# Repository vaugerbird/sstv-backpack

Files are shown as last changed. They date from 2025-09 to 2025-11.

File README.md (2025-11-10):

# sstv-backpack
## A ESP32-CAM SSTV backpack for the Baofeng UV-5R and others!

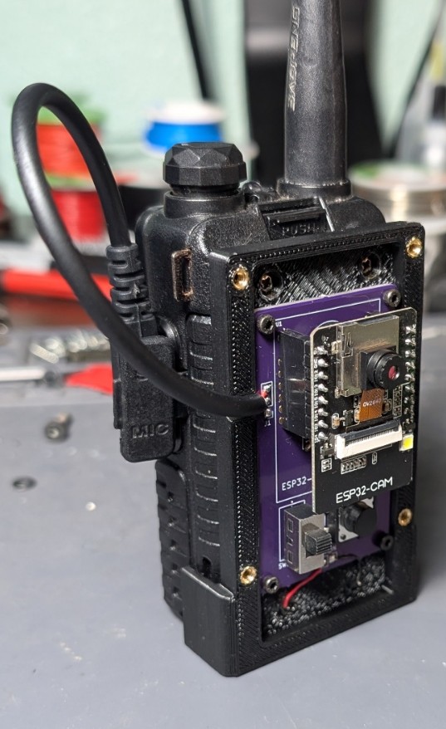
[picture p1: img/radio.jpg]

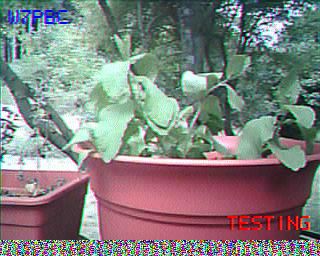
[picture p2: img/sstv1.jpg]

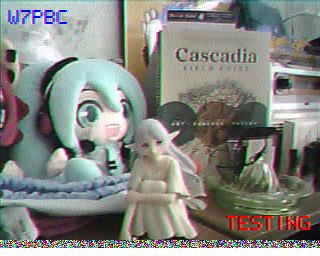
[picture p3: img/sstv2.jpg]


## Project Description
### Turn your HT into a point-and-shoot camera!
This project relies on using an ESP32 connected to a handheld transceiver to send SSTV (Slow Scan TeleVision) images. Any combination of HT and ESP32-CAM can send a picture, but the hardware in this repository is specifically designed to work!

To decode the images, another radio must be used and connected to any device that can run a decoder program. I personally use MMSSTV on my PC with a USB soundcard, or my phone running Robot36 and listening to the radio with the microphone. 

Here's some questions I've been asked in the past:
* **Why?**
    * This is a term project that I created for my college ARC that I'm the president of! We are currently assembling v1.1 and we plan on using the completed projects to do a SSTV scavenger hunt. This consists of a list of things to take pictures of around campus, where the hunter will take a picture of the required object, send the image back to the control room (clubroom), and the point will be awarded to the hunter/team!
* **How does this work?**
    * In short, the ESP32-CAM captures a frame, converts the image into the appropriate encoded audio for SSTV, keys the PTT on the HT, and plays the audio through the microphone port. The specifics of the encoding process are somewhat black magic to me as I didn't create the underlying code, but as far as I understand, the encoding is done by applying a few math functions to the pixels stored in the framebuffer, and converted into audio.

## Hardware Revisions
I currently have 2 hardware revisions available, with a 3rd planned: 
1. v1.0:
    * Mostly through-hole and completely hand-solderable
    * Simplest version with only a voltage regulator circuit, PTT circuit, 2 switches, a buzzer, and the ESP32-CAM
    * Requires external board for flashing and a serial monitor
2. v1.1: 
    * 2 sub-versions:
        * v1.1.1: CH340C version, uses the CH340C for USB-to-UART and has CC resistors for full USB type C compatibility.
        * v1.1.0: FT231XS version, uses the FTDI FT231XS for USB-to-UART and does **not** have CC resistors. I don't recommend this version for many reasons, unless it is difficult to get the CH340C. 
    * Still mostly through-hole and hand-solderable, albeit with some fine-pitch components like the USB-to-UART chip.
    * Retains all the same functionality of v1.0, but adds a USB-to-Serial chip for flashing and a serial monitor.
    * The board is quite cramped and may be hard to work with.
3. v1.2 (WIP):
    * Switch to a mostly top-mounted SMD design, while still being hand-solderable
    * Retain all features of the v1.1 board
    * Maybe add battery charging circuitry?

## Assembly Instructions
### Better (printable) instructions coming soon!
1. Upload your desired [Gerber](./hardware/gerbers/) file to your favorite PCB manufacturer. I recommend OSHPark for US-made, decent-priced priced small-batch PCBs. JLCPCB or PCBWay are both great for cheap, high quality PCBs, if you don't mind waiting.

2. Order the required parts using the proper BOM for [v1.0](./hardware/v1.0/sstv-backpack-v1.0.1.csv) or [v1.1](./hardware/v1.1/sstv-backpack-v1.1.1.csv) from your favorite parts supplier.

3. Once all parts arrive, assemble the board. There isn't much of a technique to it, just start with the lowest profile parts first like the diodes, resistors, and chips, and work your way up.

4. Once the board is complete, print the case using one of the included [STLs](./hardware/case). Currently, the Baofeng UV-5R is the only supported radio, but the Inventor 2025 and STEP files are included, and help with additional radio models is always appreciated!

    * I used the standard settings (0.2mm) on my print, with supports on, and the case interior facing the build plate.

    * The case requires these additional parts:
        * 4 - M3 brass het set inserts
        * 4 - M3 x 6mm screws (preferably hex head)
        * 4 - M2 x 4mm screws
        * 1 - Radio cable (I just cut the end off of a cheap Baofeng speaker-mic, it was cheaper than using an unterminated cable.)

5. After you have the hardware assembled, the next thing to do is upload the code!

## Programming Instructions
1. Ensure that you have this link added to the 3rd party boards section of the Arduino IDE (Found under File -> Preferences -> Additional board manager URLs):
```
https://dl.espressif.com/dl/package_esp32_index.json
```

2. From the board manager, install the newest version of the ESP32 board definitions.

3. Set the board model to "AI Thinker ESP32-CAM" and select the appropriate COM port.

4. Change the text options on lines 37 and 38 of [sstv-backpack.ino](./code/sstv-backpack.ino) to reflect your callsign and desired splash text.
    * The color of the top and bottom text can be changed with the definitions in lines 24-31. 

5. Uncomment line 21 ```#define USE_FLASH``` if you want to use the flash LED (Turns on a high intensity white LED on when framegrabbing).

6. At line 447, set `1 = HIGH` or `0 = LOW` properly reflect your CAPT_BTN wiring (GND for LOW, or +3.3V for HIGH)

7. Between line 452-456, choose the correct button pull-up/pull-down configuration. The button is set to pull-up by default to mirror the PCBs. (Button connects to GND when pressed)

8. Inside the "camera.h" file you can choose between two profiles, DAYLIGHT and HOME. Feel free to modify settings to best suit your case. 
	* Notes from IU5HKU:
		* Keep in mind that this cheap sensor struggles a lot in poor light scenarios, so don't expect a picture like your Fujifilm camera.
		* A quick search online can lead you towards the proper settings values you need.

9. All the board settings can be left alone except for selecting the correct COM port.

10. Upload the code!

## Contributors
 A huge thank you to our contributors for this project! I'm pretty bad with code so all help is greatly appreciated!

 * [IU5HKU / Marco](https://github.com/IU5HKU) - Updated the code to work with the newest version of the ESP32 board definition and improved the readability/usability of the code!
 * [IU5HKU / Marco](https://github.com/IU5HKU) - Updated the code to work with deepsleep/wakeup ESP32 functions (maximize battery life).

## Licensing
* The [main program](./code/sstv-backpack.ino) and [supporting libraries](./code/) are licensed as CC BY-NC-SA 4.0 and are based on the program/libraries from [desafioinventor](https://www.instructables.com/SSTV-Capsule-V2-for-High-Altitude-Balloons/) on Instructables. 
* The case design is roughly based on [this design](https://www.thingiverse.com/thing:5270394) by HStakhiv on [Thingiverse](https://www.thingiverse.com/hstakhiv/designs). The original is licensed under CC BY. My case design falls under the GPL-2.0 license.
* The remaining contents of this repository are designed by me (and contributors!), and are licensed under the GPL-2.0 license.

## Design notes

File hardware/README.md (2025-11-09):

# Hardware
## Currently there are 3 revisions:
* v1.0(.1)
    * Simplest version
    * The board only acts as a voltage regulator, PTT circuit, and carrier for the major parts
* v1.1
    * More complex
    * The board contains the voltage regulator circuit, USB flashing circuit, and PTT circuit
* v1.2
    * Same complexity as v1.1, contains mostly SMD parts

## HW Issues
* v1.0(.1):
    * This board is incapable of flashing the ESP32 or using serial monitor as there is no USB-to-UART chip present. Flashing has to be done with a dedicated programmer and debugging is very difficult. 
* v1.1.0:
    * ~~No CC resistors are present (or really possible) for the USB-C port. This is due to physical restraints of through-hole components, and means the board will not receive power from a USB-C to USB-C cable.~~ Fixed with v1.1.1
    * ~~Powering the board from the radio and connecting USB data is possible, and won't break anything as power is diode-protected, but is not recommended.~~ Fixed with v1.1.1
* v1.2:
    * No issues have been found; this revision of the board has not yet been tested.

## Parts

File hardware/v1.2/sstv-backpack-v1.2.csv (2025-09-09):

Reference | Qty | Value | Part Number | Footprint | Notes
BZ1 | 1 | Buzzer | PS1240P02BT | Buzzer_Beeper:Buzzer_TDK_PS1240P02BT_D12.2mm_H6.5mm
C1,C2 | 2 | 1uF | TAP105K020SCS | Capacitor_THT:C_Disc_D3.4mm_W2.1mm_P2.50mm
C3,C4 | 2 | 47pF | K470J15C0GF5TL2 | Capacitor_THT:C_Disc_D4.7mm_W2.5mm_P5.00mm
C5 | 1 | 10nF | K103K10X7RF5UL2 | Capacitor_THT:C_Disc_D4.7mm_W2.5mm_P5.00mm
C6 | 1 | 100nF | K104K15X7RF5TL2 | Capacitor_THT:C_Disc_D4.7mm_W2.5mm_P5.00mm
D1,D2 | 2 | 1N5819 | 1N5819 | Diode_THT:D_DO-41_SOD81_P7.62mm_Horizontal
D3,D4 | 2 | 1N4148 | 1N4148 | Diode_THT:D_DO-41_SOD81_P7.62mm_Horizontal
J1 | 1 | Conn_01x03_Pin | Optional | Connector_PinHeader_2.54mm:PinHeader_1x03_P2.54mm_Vertical
J2 | 1 | Conn_01x02_Pin | Optional | Connector_PinHeader_2.54mm:PinHeader_1x02_P2.54mm_Vertical
J3 | 1 | 2172034-1 | 2172034-1 | 2172034-1:TE_2172034-1
R1,R2 | 2 | 27Ω | MFR-25FTE52-27R | Resistor_THT:R_Axial_DIN0207_L6.3mm_D2.5mm_P7.62mm_Horizontal
SW1 | 1 | SW_Push | PTS125SM73SMTR21M LFS
SW2 | 1 | SLW-1276864-4A-D | SLW-1276864-4A-D | SwitchSPDT:SW_SLW-1276864-4A-D
U1 | 1 | ESP32-CAM | See note → | ESP32-CAM:ESP32-CAM | I recommend ordering this from Amazon
U1 | 2 | 1X8 FEM HEADERS | PPTC081LFBN-RC | ESP32-CAM:ESP32-CAM
U2 | 1 | FT231XS | FT231XS-R | Package_SO:SSOP-20_3.9x8.7mm_P0.635mm
VR1 | 1 | LP38693DT-5.0 | LP38691DTX-5.0/NOPB | Package_TO_SOT_SMD:TO-252-2

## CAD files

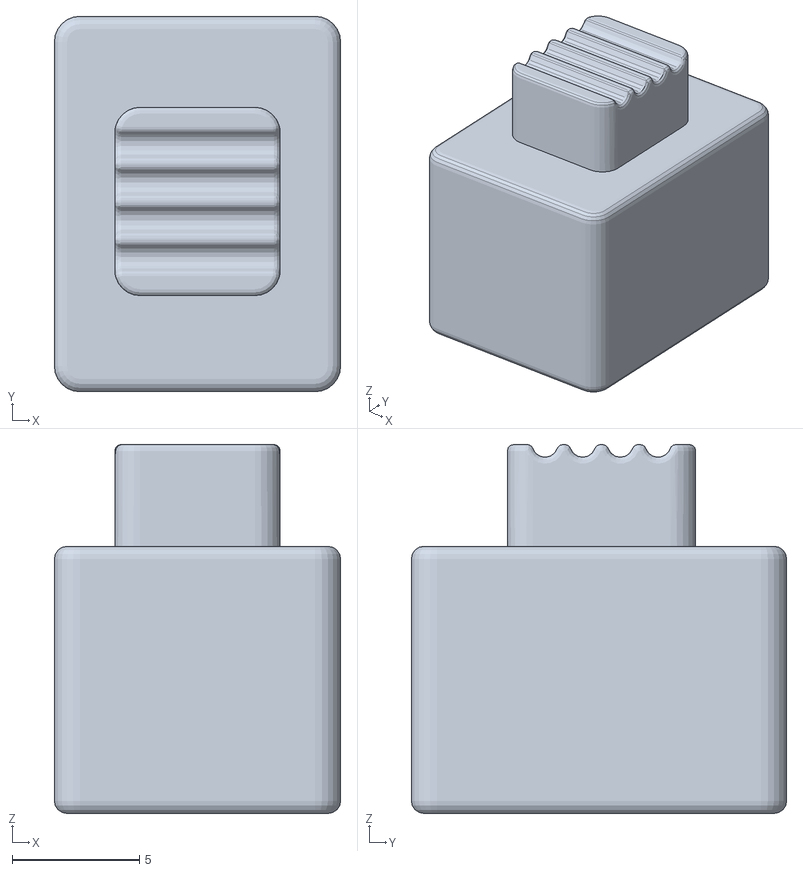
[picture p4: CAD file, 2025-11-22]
hardware/case/Universal/switch.stl
11.2 x 14.8 x 14.5

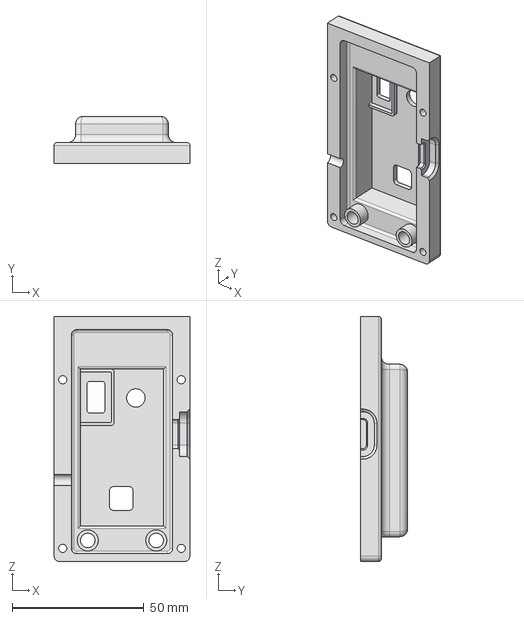
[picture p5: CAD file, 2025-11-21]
hardware/case/UV-5R/STEP/uv-5r-front.stp
51.5 x 18.0 x 93.0 mm

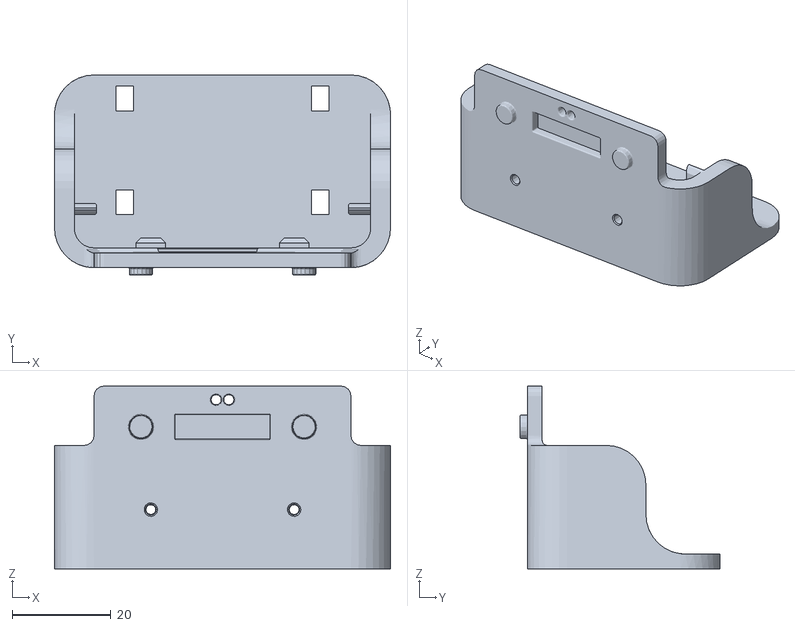
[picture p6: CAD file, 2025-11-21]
hardware/case/UV-5RM/5RM_batt_conn.stl
68.0 x 40.5 x 37.0

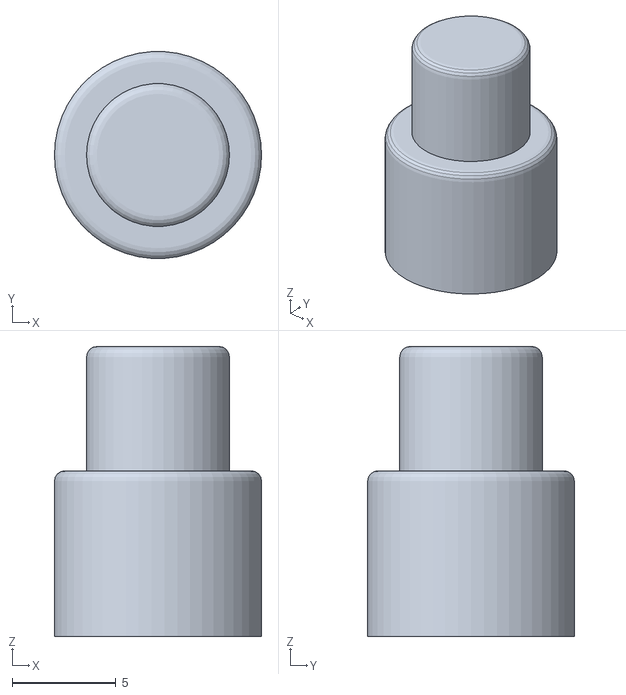
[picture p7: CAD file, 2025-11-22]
hardware/case/Universal/button.stl
10.0 x 9.98 x 14.0

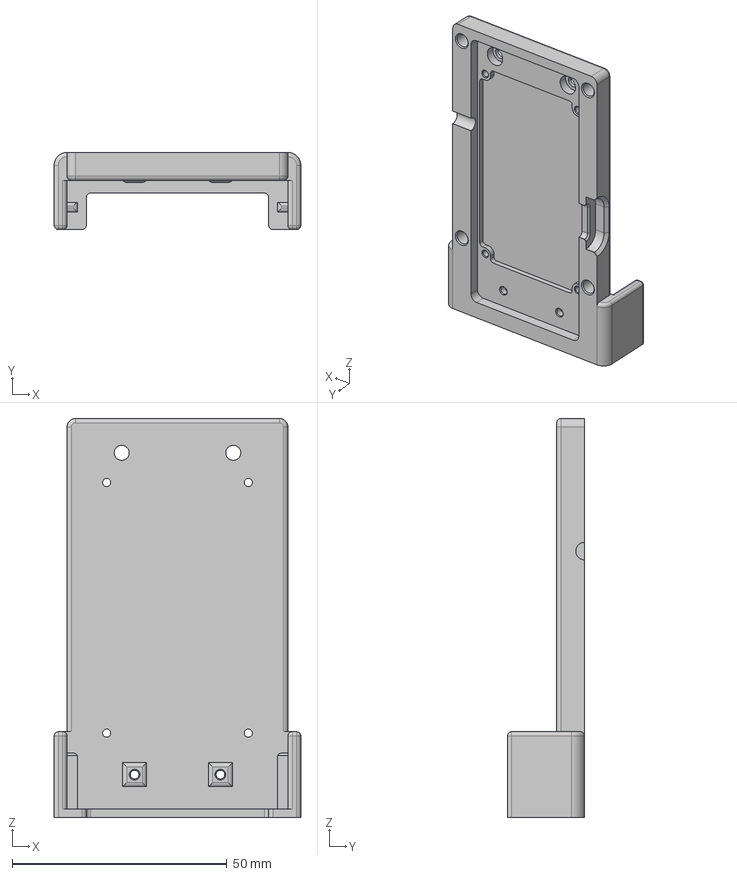
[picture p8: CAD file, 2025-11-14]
hardware/case/UV-5R/STEP/uv-5r-back.stp
57.5 x 18.0 x 93.0 mm

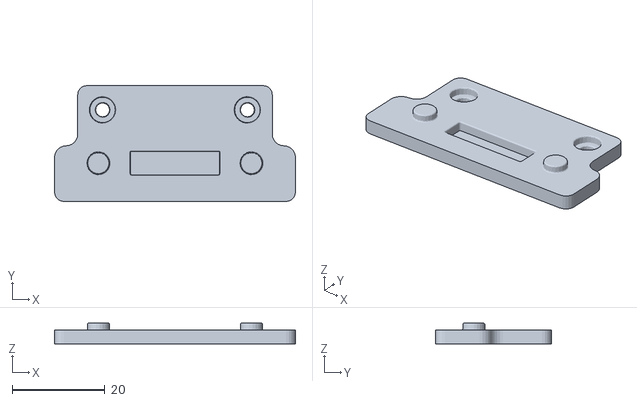
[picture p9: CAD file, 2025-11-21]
hardware/case/UV-5RM/5RM_belt_clip.stl
52.0 x 25.0 x 4.50

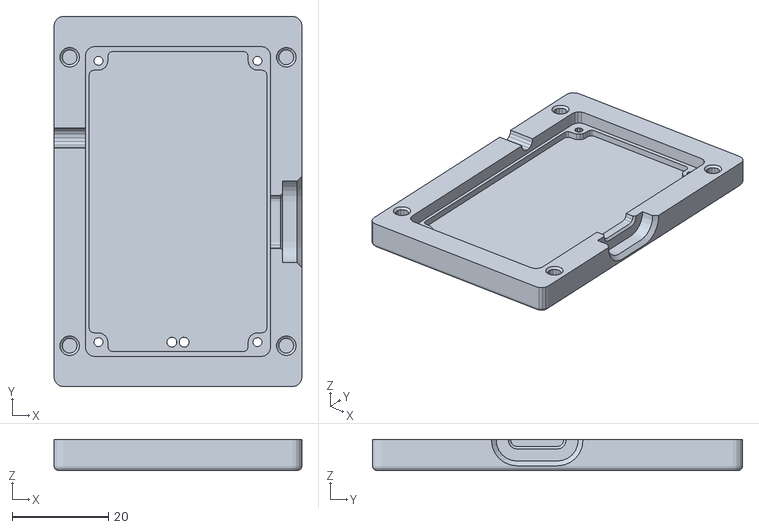
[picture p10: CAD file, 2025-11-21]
hardware/case/Universal/universal_case_back.stl
51.5 x 76.9 x 6.50

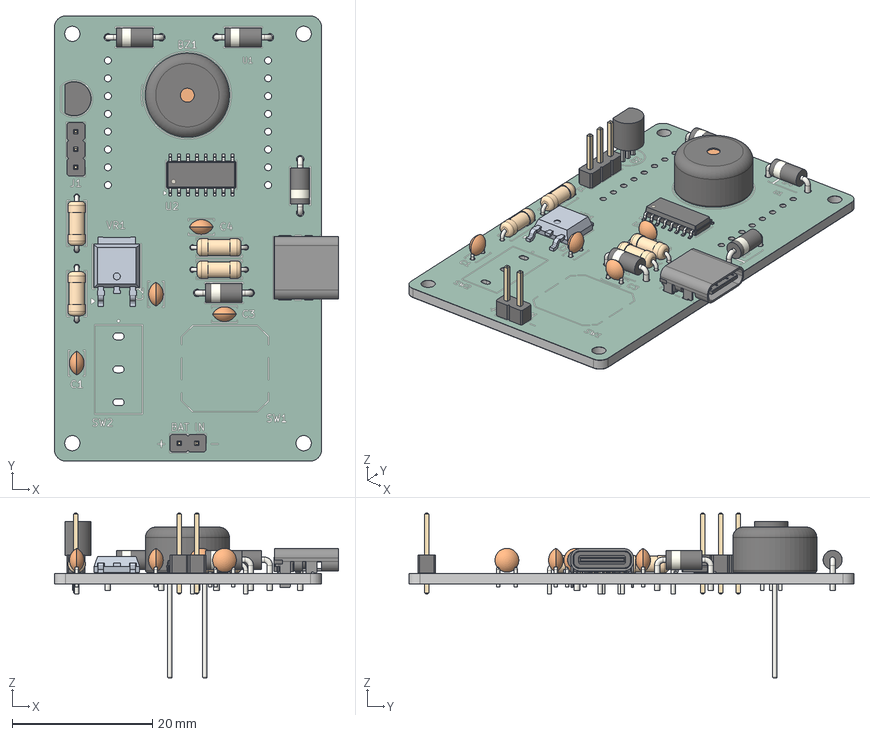
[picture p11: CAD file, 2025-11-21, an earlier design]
hardware/v1.1/sstv-backpack.step
40.5 x 63.5 x 23.5 mm
sstv-backpack 1.1.1
Buzzer_TDK_PS1240P02BT_D12.2mm_H6.5mm
R_Axial_DIN0207_L6.3mm_D2.5mm_P7.62mm_Horizontal x 4
D_DO-41_SOD81_P7.62mm_Horizontal x 4
C_Disc_D3.4mm_W2.1mm_P2.50mm x 4
PinHeader_1x02_P2.54mm_Vertical
SOIC-16_3.9x9.9mm_P1.27mm
PinHeader_1x03_P2.54mm_Vertical
USB_C_Receptacle_GCT_USB4085
TO-92_Inline
sstv-backpack-v1.1.1_silkscreen x 2
sstv-backpack-v1.1.1_soldermask x 2
sstv-backpack-v1.1.1_PCB

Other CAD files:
hardware/case/UV-5R/Inventor (2025)/uv-5r-back.ipt
hardware/case/UV-5R/Inventor (2025)/uv-5r-front.ipt
hardware/case/UV-5R/uv-5r-back.stl
hardware/case/UV-5R/uv-5r-front.stl
hardware/case/UV-5RM/Inventor (2025)/5RM_batt_conn.ipt
hardware/case/UV-5RM/Inventor (2025)/5RM_belt_clip.ipt
hardware/case/Universal/Inventor (2025)/button.ipt
hardware/case/Universal/Inventor (2025)/switch.ipt
hardware/case/Universal/Inventor (2025)/universal_case_back.ipt
hardware/v1.1/sstv-backpack/Buzzer_TDK_PS1240P02BT_D12.2mm_H6.5mm.ipt
hardware/v1.1/sstv-backpack/C_Disc_D3.4mm_W2.1mm_P2.50mm.ipt
hardware/v1.1/sstv-backpack/D_DO-41_SOD81_P7.62mm_Horizontal.ipt
hardware/v1.1/sstv-backpack/PinHeader_1x02_P2.54mm_Vertical.ipt
hardware/v1.1/sstv-backpack/PinHeader_1x03_P2.54mm_Vertical.ipt
hardware/v1.1/sstv-backpack/R_Axial_DIN0207_L6.3mm_D2.5mm_P7.62mm_Horizontal.ipt
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

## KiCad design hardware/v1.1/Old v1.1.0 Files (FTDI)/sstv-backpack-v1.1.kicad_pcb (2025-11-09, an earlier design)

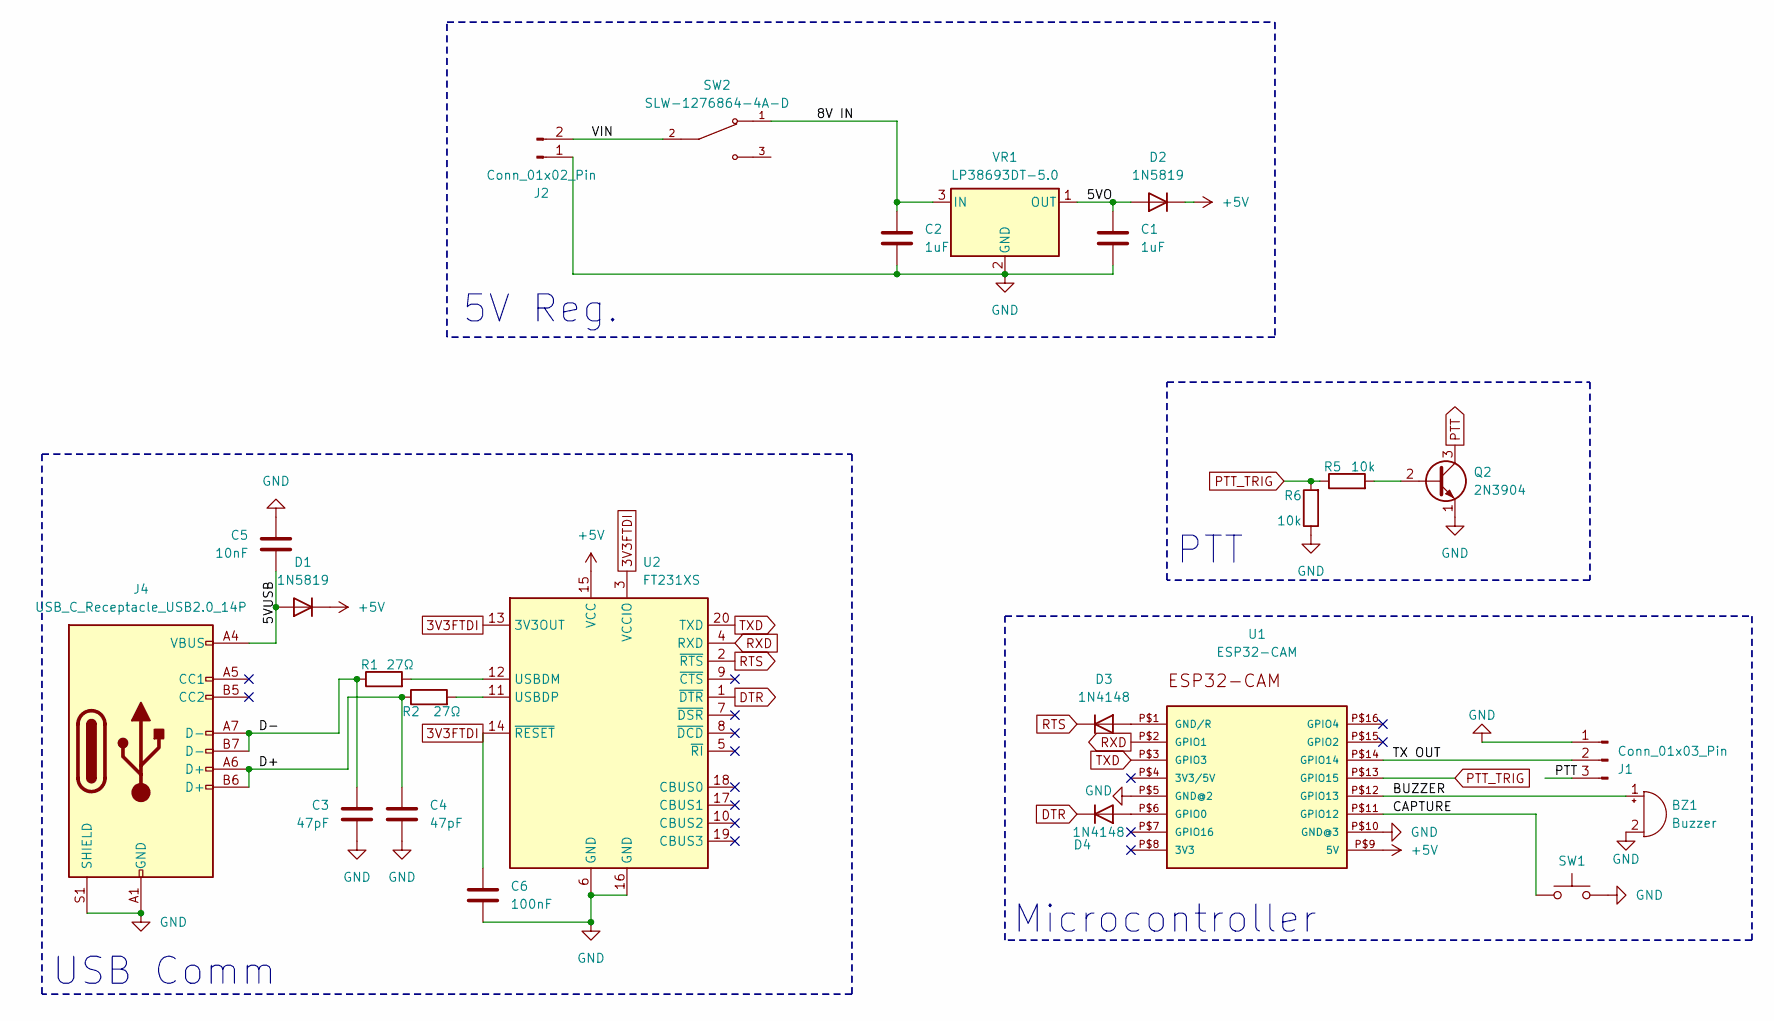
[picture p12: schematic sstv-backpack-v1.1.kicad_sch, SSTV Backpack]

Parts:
BZ1: Buzzer; Buzzer_TDK_PS1240P02BT_D12.2mm_H6.5mm
C1, C2: 1uF; C_Disc_D3.4mm_W2.1mm_P2.50mm
C3, C4: 47pF; C_Disc_D4.7mm_W2.5mm_P5.00mm
C5: 10nF; C_Disc_D4.7mm_W2.5mm_P5.00mm
C6: 100nF; C_Disc_D4.7mm_W2.5mm_P5.00mm
D1, D2: 1N5819; D_DO-41_SOD81_P7.62mm_Horizontal
D3, D4: 1N4148; D_DO-41_SOD81_P7.62mm_Horizontal
J1: Conn_01x03_Pin; PinHeader_1x03_P2.54mm_Vertical
J2: Conn_01x02_Pin; PinHeader_1x02_P2.54mm_Vertical
J4: USB_C_Receptacle_USB2.0_14P; USB_C_Receptacle_GCT_USB4085
Q2: 2N3904; TO-92_Inline
R1, R2: 27Ω; R_Axial_DIN0207_L6.3mm_D2.5mm_P7.62mm_Horizontal
R5, R6: 10k; R_Axial_DIN0207_L6.3mm_D2.5mm_P7.62mm_Horizontal
SW1: SW_Push
SW2: SLW-1276864-4A-D; SW_SLW-1276864-4A-D; PARTREV 1.01
U1: ESP32-CAM
U2: FT231XS; SSOP-20_3.9x8.7mm_P0.635mm
VR1: LP38693DT-5.0; TO-252-2

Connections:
3V3FTDI: C6.1, U2.3 (VCCIO), U2.13 (3V3OUT), U2.14 (~RESET)
+5V: D1.1 (K), D2.1 (K), U1.P$9 (5V), U2.15 (VCC)
/5VO: C1.1, D2.2 (A), VR1.1 (OUT)
/5VUSB: C5.2, D1.2 (A), J4.A4 (VBUS), J4.A9 (VBUS), J4.B4 (VBUS), J4.B9 (VBUS)
/8V IN: C2.1, SW2.1, VR1.3 (IN)
/BUZZER: BZ1.1 (+), U1.P$12 (GPIO13)
/CAPTURE: SW1.1, U1.P$11 (GPIO12)
/D+: C4.1, J4.A6 (D+), J4.B6 (D+), R2.1
/D-: C3.1, J4.A7 (D-), J4.B7 (D-), R1.1
/TX OUT: J1.2, U1.P$14 (GPIO14)
/VIN: J2.2, SW2.2
DTR: D4.1 (K), U2.1 (~DTR)
GND: BZ1.2 (-), C1.2, C2.2, C3.2, C4.2, C5.1, C6.2, J1.1, J2.1, J4.A1 (GND), J4.A12 (GND), J4.B1 (GND), J4.B12 (GND), J4.S1 (SHIELD), Q2.1 (E), R6.1, SW1.2, U1.P$5 (GND@2), U1.P$10 (GND@3), U2.6 (GND), U2.16 (GND), VR1.2 (GND)
unnamed: D3.2 (A), U1.P$1 (GND/R)
unnamed: D4.2 (A), U1.P$6 (GPIO0)
unnamed: Q2.2 (B), R5.2
unnamed: R1.2, U2.12 (USBDM)
unnamed: R2.2, U2.11 (USBDP)
PTT: J1.3, Q2.3 (C)
PTT_TRIG: R5.1, R6.2, U1.P$13 (GPIO15)
RTS: D3.1 (K), U2.2 (~RTS)
RXD: U1.P$2 (GPIO1), U2.4 (RXD)
TXD: U1.P$3 (GPIO3), U2.20 (TXD)

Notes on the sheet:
5V Reg.
Microcontroller
USB Comm
PTT

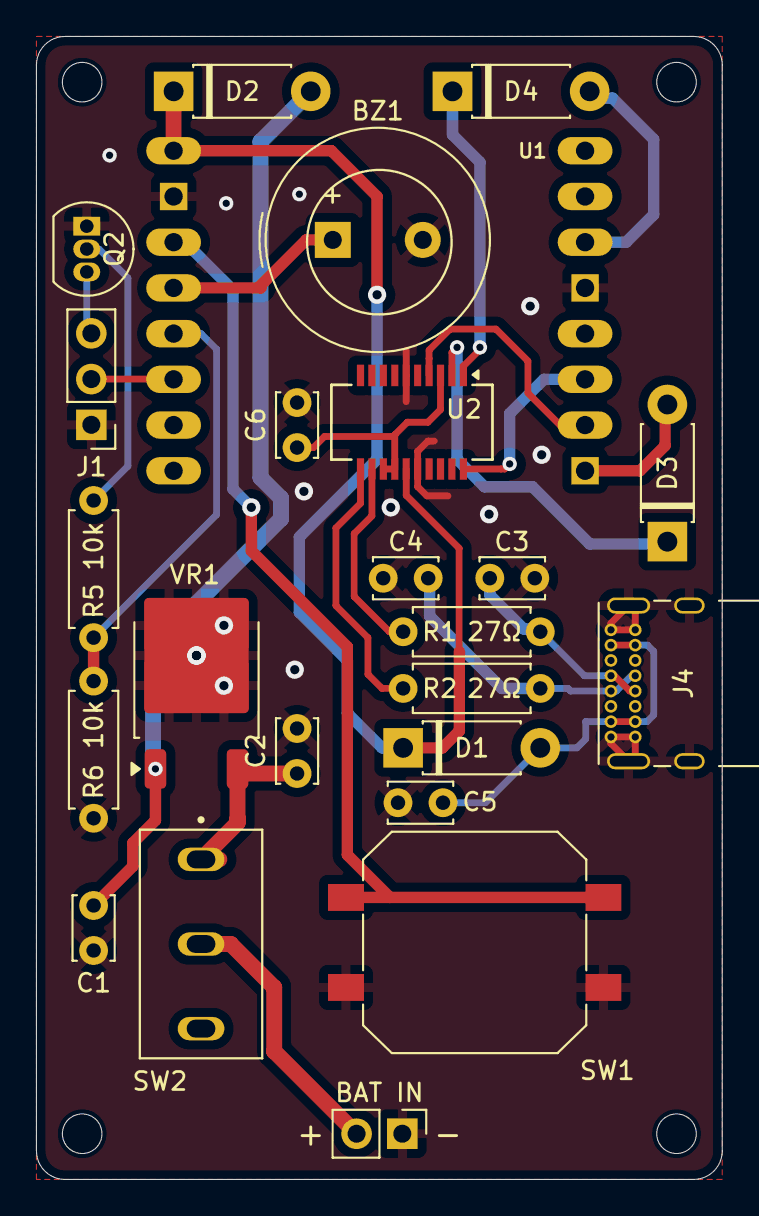
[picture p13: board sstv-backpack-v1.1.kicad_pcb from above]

Board: 2 copper layers, 38.1 x 63.5 mm, 24 parts (0 on the bottom side), 23 nets.

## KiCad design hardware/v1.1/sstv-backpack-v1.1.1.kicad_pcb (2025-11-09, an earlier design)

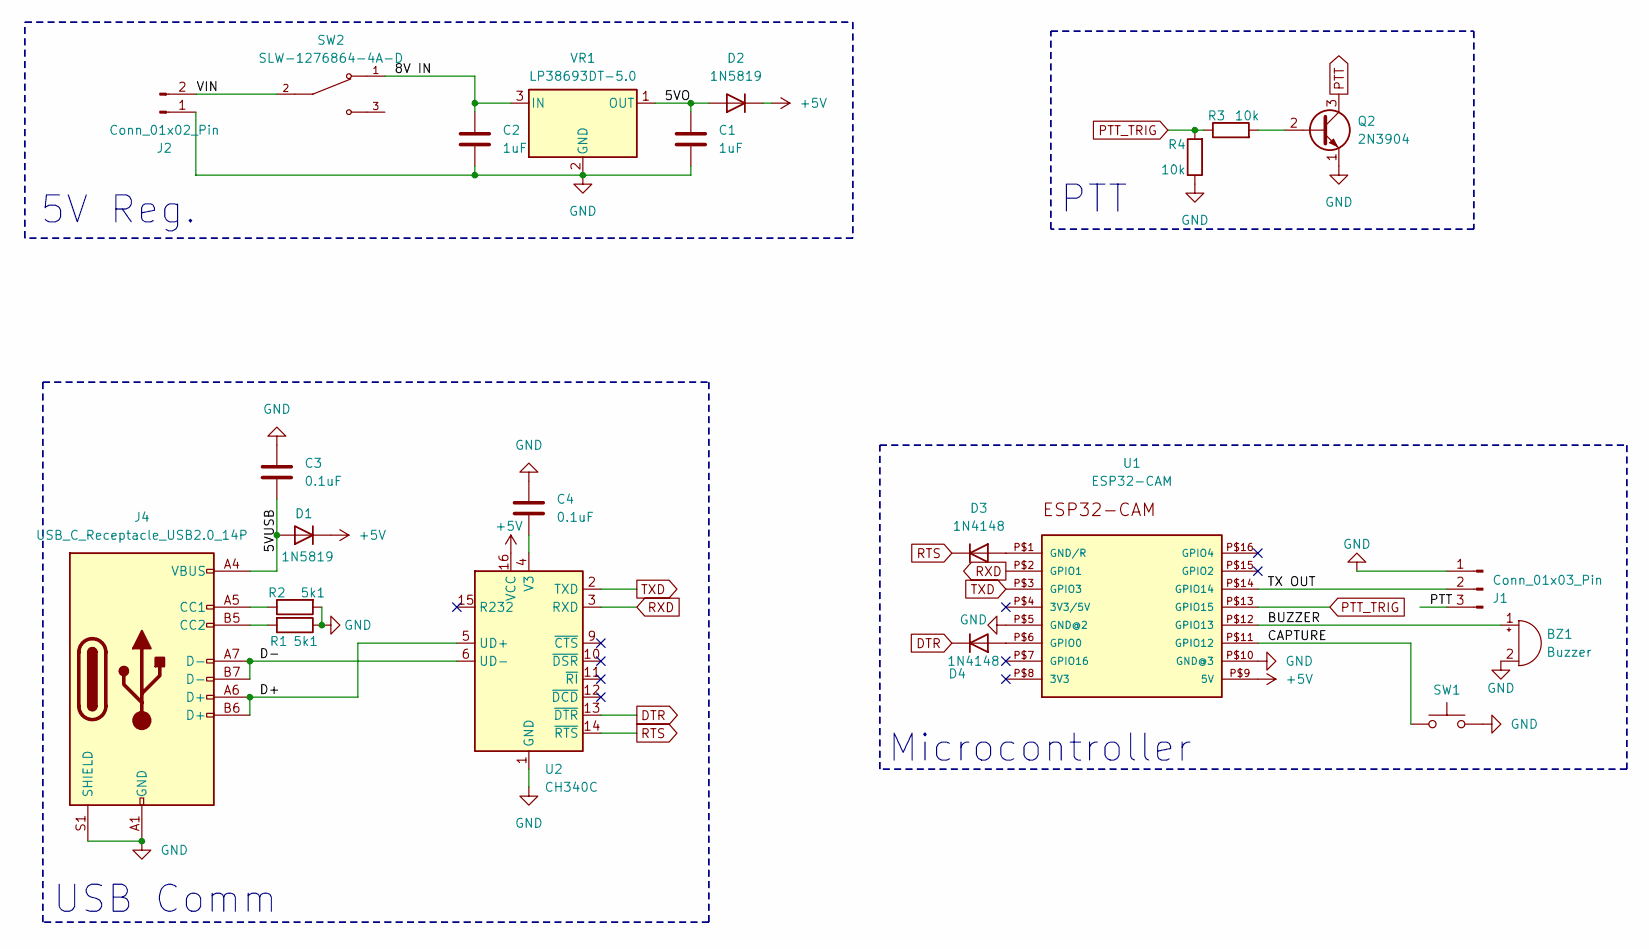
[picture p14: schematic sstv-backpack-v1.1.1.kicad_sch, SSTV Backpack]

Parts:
BZ1: Buzzer; Buzzer_TDK_PS1240P02BT_D12.2mm_H6.5mm
C1, C2: 1uF; C_Disc_D3.4mm_W2.1mm_P2.50mm
C3, C4: 0.1uF; C_Disc_D3.4mm_W2.1mm_P2.50mm
D1, D2: 1N5819; D_DO-41_SOD81_P7.62mm_Horizontal
D3, D4: 1N4148; D_DO-41_SOD81_P7.62mm_Horizontal
J1: Conn_01x03_Pin; PinHeader_1x03_P2.54mm_Vertical
J2: Conn_01x02_Pin; PinHeader_1x02_P2.54mm_Vertical
J4: USB_C_Receptacle_USB2.0_14P; USB_C_Receptacle_GCT_USB4085
Q2: 2N3904; TO-92_Inline
R1, R2: 5k1; R_Axial_DIN0207_L6.3mm_D2.5mm_P7.62mm_Horizontal
R3, R4: 10k; R_Axial_DIN0207_L6.3mm_D2.5mm_P7.62mm_Horizontal
SW1: SW_Push
SW2: SLW-1276864-4A-D; SW_SLW-1276864-4A-D; PARTREV 1.01
U1: ESP32-CAM
U2: CH340C; SOIC-16_3.9x9.9mm_P1.27mm
VR1: LP38693DT-5.0; TO-252-2

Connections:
+5V: D1.1 (K), D2.1 (K), U1.P$9 (5V), U2.16 (VCC)
/5VO: C1.1, D2.2 (A), VR1.1 (OUT)
/5VUSB: C3.2, D1.2 (A), J4.A4 (VBUS), J4.A9 (VBUS), J4.B4 (VBUS), J4.B9 (VBUS)
/8V IN: C2.1, SW2.1, VR1.3 (IN)
/BUZZER: BZ1.1 (+), U1.P$12 (GPIO13)
/CAPTURE: SW1.1, U1.P$11 (GPIO12)
/D+: J4.A6 (D+), J4.B6 (D+), U2.5 (UD+)
/D-: J4.A7 (D-), J4.B7 (D-), U2.6 (UD-)
/TX OUT: J1.2, U1.P$14 (GPIO14)
/VIN: J2.2, SW2.2
DTR: D4.1 (K), U2.13 (~DTR)
GND: BZ1.2 (-), C1.2, C2.2, C3.1, C4.1, J1.1, J2.1, J4.A1 (GND), J4.A12 (GND), J4.B1 (GND), J4.B12 (GND), J4.S1 (SHIELD), Q2.1 (E), R1.1, R2.2, R4.1, SW1.2, U1.P$5 (GND@2), U1.P$10 (GND@3), U2.1 (GND), VR1.2 (GND)
unnamed: D3.2 (A), U1.P$1 (GND/R)
unnamed: D4.2 (A), U1.P$6 (GPIO0)
unnamed: J4.A5 (CC1), R2.1
unnamed: J4.B5 (CC2), R1.2
unnamed: Q2.2 (B), R3.2
unnamed: C4.2, U2.4 (V3)
PTT: J1.3, Q2.3 (C)
PTT_TRIG: R3.1, R4.2, U1.P$13 (GPIO15)
RTS: D3.1 (K), U2.14 (~RTS)
RXD: U1.P$2 (GPIO1), U2.3 (RXD)
TXD: U1.P$3 (GPIO3), U2.2 (TXD)

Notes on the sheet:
5V Reg.
Microcontroller
USB Comm
PTT

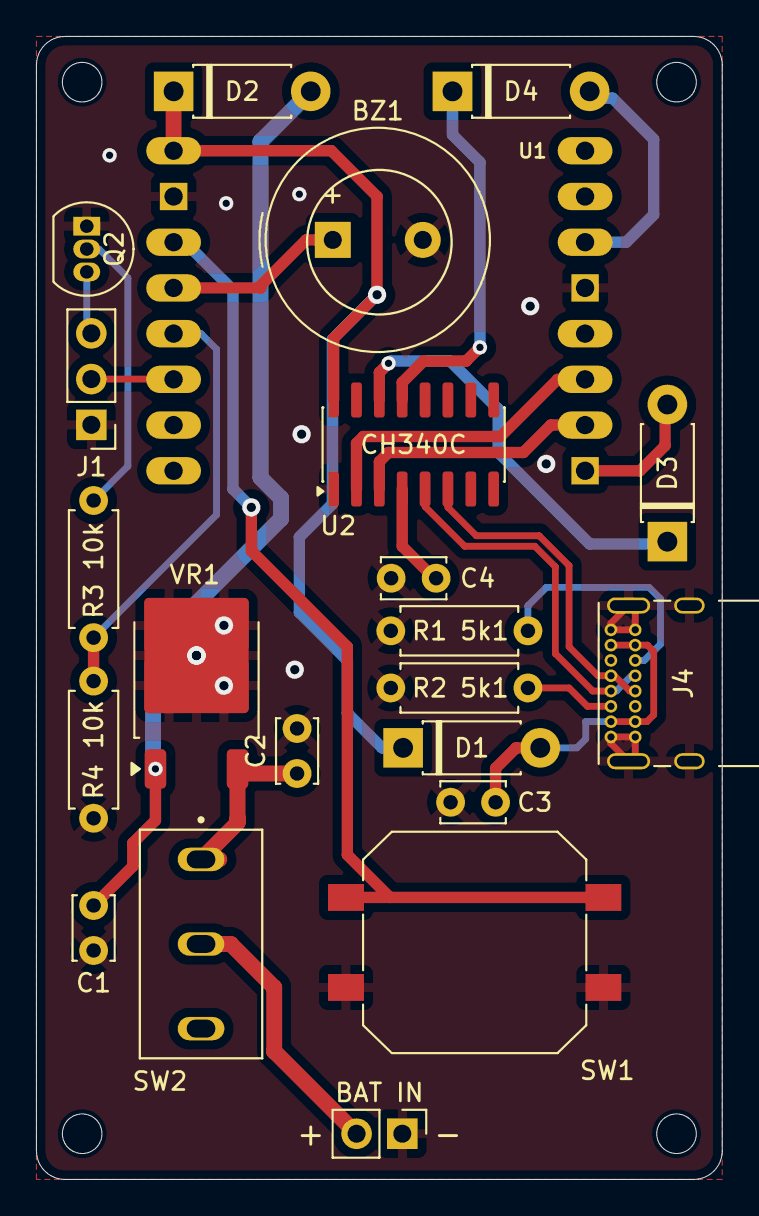
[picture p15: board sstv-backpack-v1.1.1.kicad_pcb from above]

Board: 2 copper layers, 38.1 x 63.5 mm, 22 parts (0 on the bottom side), 23 nets.

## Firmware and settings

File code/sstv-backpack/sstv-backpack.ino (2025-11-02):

#include <driver/ledc.h>
#include "camera.h"
#include "sin256.h"
#include <esp_task_wdt.h>
#include <driver/rtc_io.h>
#include <WiFi.h>

#define BELL202_BAUD 1200
#define F_SAMPLE ((BELL202_BAUD * 32) * 0.93) // ≈ 35712 Hz
#define FTOFTW (4294967295 / F_SAMPLE)
#define TIME_PER_SAMPLE (1000.0/F_SAMPLE)
#define uS_TO_S_FACTOR 1000000
#define TIME_TO_SLEEP  5

#define LED_FLASH       4
#define LED_RED         33
#define SPEAKER_OUTPUT  14
#define PTT_PIN         15      // Pin for PTT (HIGH = active)
#define BUZZER_PIN      13   // Pin for indication buzzer
#define CAPT_BTN        GPIO_NUM_12     // Pin for button to activate capture
//#define USE_FLASH     // Uncomment to use the onboard high intensity white LED as flash

// TOP STRING COLOR (default cyan, the most readable)
#define TOP_R  0
#define TOP_G  255
#define TOP_B  255

// BOTTOM STRING COLOR (default cyan, the most readable)
#define BTM_R  0
#define BTM_G  255
#define BTM_B  255

bool capt_frame = false;

int start = 0;

String overlayTextTop = "CALLSIGN_HERE";    // Upper left
String overlayTextBottom = "SUBTEXT_HERE"; // Lower right

volatile uint32_t FTW = FTOFTW * 1000;
volatile uint32_t PCW = 0;
volatile uint32_t TFLAG = 0;

#define FT_1000 (uint32_t) (1000 * FTOFTW)
#define FT_1100 (uint32_t) (1100 * FTOFTW)
#define FT_1200 (uint32_t) (1200 * FTOFTW)
#define FT_1300 (uint32_t) (1300 * FTOFTW)
#define FT_1500 (uint32_t) (1500 * FTOFTW)
#define FT_1900 (uint32_t) (1900 * FTOFTW)
#define FT_2200 (uint32_t) (2200 * FTOFTW)
#define FT_2300 (uint32_t) (2300 * FTOFTW)
#define FT_SYNC (uint32_t) (FT_1200)

#define MAX_WIDTH 320
#define MAX_HEIGHT 256

class SSTV_config_t {
  public:
    uint8_t vis_code;
    uint32_t width;
    uint32_t height;
    float line_time;
    float h_sync_time;
    float v_sync_time;
    float c_sync_time;
    float left_margin_time;
    float visible_pixels_time;
    float pixel_time;
    bool color;
    bool martin;
    bool robot;

    SSTV_config_t(uint8_t v) {
      vis_code = v;
      switch (vis_code) {
        case 2: // Robot B&W8
          robot = true; martin = false; color = false;
          width = 160; height = 120;
          line_time = 67.025; h_sync_time = 30.0; v_sync_time = 6.5;
          left_margin_time = 1.6;
          visible_pixels_time = line_time - v_sync_time - left_margin_time;
          pixel_time = visible_pixels_time / width;
          break;
        case 44: // Martin M1
          robot = false; martin = true; color = true;
          width = 320; height = 240;
          line_time = 446.4460001; h_sync_time = 30.0; v_sync_time = 4.862;
          c_sync_time = 0.572; left_margin_time = 0.0;
          visible_pixels_time = line_time - v_sync_time - left_margin_time - (2 * c_sync_time);
          pixel_time = visible_pixels_time / (width * 3);
          break;
      }
    }
};

camera_fb_t* fb;

SSTV_config_t* currentSSTV;

volatile uint16_t rasterX = 0;
volatile uint16_t rasterY = 0;
volatile uint8_t SSTVseq = 0;
double SSTVtime = 0;
double SSTVnext = 0;
uint8_t VISsr = 0;
uint8_t VISparity;
uint8_t HEADERptr = 0;
static uint32_t SSTV_HEADER[] = {FT_2300, 100, FT_1500, 100, FT_2300, 100, FT_1500, 100, FT_1900, 300, FT_1200, 10, FT_1900, 300, FT_1200, 30, 0, 0};
uint8_t SSTV_RUNNING = 0;

uint8_t *rgb_buf = NULL;
uint32_t rgb_buf_len;
uint16_t rgb_width;
uint16_t rgb_height;

TaskHandle_t sampleHandlerHandle;

void IRAM_ATTR audioISR() {
  PCW += FTW;
  TFLAG = 1;
}

/*******************************************************
 * FUNCTION: print_wakeup_reason
 * DESCRIPTION: Prints the cause of the ESP32 waking up
 * from Deep Sleep (Timer, external signal, etc.) to the serial monitor.
 * INPUT: None
 * OUTPUT: None
 *******************************************************/
void print_wakeup_reason(){
  esp_sleep_wakeup_cause_t wakeup_reason;

  wakeup_reason = esp_sleep_get_wakeup_cause();

  switch(wakeup_reason)
  {
    case ESP_SLEEP_WAKEUP_EXT0 : 
      {
        Serial.println("Wakeup caused by external signal using RTC_IO");
        capt_frame = true;
      }
      break;
    case ESP_SLEEP_WAKEUP_EXT1 : Serial.println("Wakeup caused by external signal using RTC_CNTL"); break;
    case ESP_SLEEP_WAKEUP_TIMER : Serial.println("Wakeup caused by timer"); break;
    case ESP_SLEEP_WAKEUP_TOUCHPAD : Serial.println("Wakeup caused by touchpad"); break;
    case ESP_SLEEP_WAKEUP_ULP : Serial.println("Wakeup caused by ULP program"); break;
    default : Serial.printf("Wakeup was not caused by deep sleep: %d\n",wakeup_reason); break;
  }
}

void sampleHandler(void *p) {
  disableCore0WDT();
  while (1) {
    if (TFLAG) {
      TFLAG = 0;
      int v = SinTableH[((uint8_t*)&PCW)[3]];
      ledcWrite(SPEAKER_OUTPUT, v); // modulate the selected pin in PWM
      SSTVtime += TIME_PER_SAMPLE;
      if (!SSTV_RUNNING || SSTVtime < SSTVnext) continue;

      switch (SSTVseq) {
        case 0: // Start
          SSTVtime = 0; HEADERptr = 0; VISparity = 0; VISsr = currentSSTV->vis_code;
          FTW = SSTV_HEADER[HEADERptr++]; SSTVnext = (float)SSTV_HEADER[HEADERptr++];
          SSTVseq++; break;
        case 1: // VIS header
          if (SSTV_HEADER[HEADERptr + 1] == 0) {
            SSTVseq++; HEADERptr = 0;
          } else {
            FTW = SSTV_HEADER[HEADERptr++]; SSTVnext += (float)SSTV_HEADER[HEADERptr++];
          }
          break;
        case 2: // VIS code
          if (HEADERptr == 7) {
            HEADERptr = 0;
            FTW = VISparity ? FT_1100 : FT_1300;
            SSTVnext += 30.0; SSTVseq++;
          } else {
            FTW = (VISsr & 0x01) ? (VISparity ^= 0x01, FT_1100) : FT_1300;
            VISsr >>= 1; SSTVnext += 30.0; HEADERptr++;
          }
          break;
        case 3: // VIS stop bit/sync0
          FTW = FT_1200; SSTVnext += 30.0 + currentSSTV->h_sync_time;
          rasterX = 0; rasterY = 0; SSTVseq = 10; break;
        case 10: // Start of line Green
          if (rasterX == currentSSTV->width) {
            rasterX = 0; FTW = FT_1500; SSTVnext += currentSSTV->c_sync_time; SSTVseq++;
          } else {
            int G = rgb_buf[1 + (rasterX * 3) + (rasterY * currentSSTV->width * 3)];
            int f = map(G, 0, 255, 1500, 2300); FTW = FTOFTW * f;
            SSTVnext += currentSSTV->pixel_time; rasterX++;
          }
          break;
        case 11: // Blue
          if (rasterX == currentSSTV->width) {
            rasterX = 0; FTW = FT_1500; SSTVnext += currentSSTV->c_sync_time; SSTVseq++;
          } else {
            int B = rgb_buf[(rasterX * 3) + (rasterY * currentSSTV->width * 3)];
            int f = map(B, 0, 255, 1500, 2300); FTW = FTOFTW * f;
            SSTVnext += currentSSTV->pixel_time; rasterX++;
          }
          break;
        case 12: // Red
          if (rasterX == currentSSTV->width) {
            rasterX = 0; rasterY++;
            if (rasterY == currentSSTV->height) {
              SSTV_RUNNING = false; SSTVseq = 0; FTW = 0; PCW = 0;
            } else {
              FTW = FT_SYNC; SSTVnext += currentSSTV->v_sync_time; SSTVseq = 10;
            }
          } else {
            int R = rgb_buf[2 + (rasterX * 3) + (rasterY * currentSSTV->width * 3)];
            int f = map(R, 0, 255, 1500, 2300); FTW = FTOFTW * f;
            SSTVnext += currentSSTV->pixel_time; rasterX++;
          }
          break;
      }
    }
  }
}

void drawText(uint8_t *rgb_buf, uint16_t width, uint16_t height, const char *text_top, const char *text_bottom) {
  if (!rgb_buf) return;

  int char_width = 10;
  int char_height = 14;
  int spacing = 2;

  const uint8_t font[36][7] = {
    {0b01110, 0b10001, 0b10001, 0b11111, 0b10001, 0b10001, 0b10001}, // A
    {0b11110, 0b10001, 0b10001, 0b11110, 0b10001, 0b10001, 0b11110}, // B
    {0b01111, 0b10000, 0b10000, 0b10000, 0b10000, 0b10000, 0b01111}, // C
    {0b11110, 0b10001, 0b10001, 0b10001, 0b10001, 0b10001, 0b11110}, // D
    {0b11111, 0b10000, 0b10000, 0b11110, 0b10000, 0b10000, 0b11111}, // E
    {0b11111, 0b10000, 0b10000, 0b11110, 0b10000, 0b10000, 0b10000}, // F
    {0b01111, 0b10000, 0b10000, 0b10011, 0b10001, 0b10001, 0b01111}, // G
    {0b10001, 0b10001, 0b10001, 0b11111, 0b10001, 0b10001, 0b10001}, // H
    {0b00100, 0b00100, 0b00100, 0b00100, 0b00100, 0b00100, 0b00100}, // I
    {0b00001, 0b00001, 0b00001, 0b00001, 0b00001, 0b10001, 0b01110}, // J
    {0b10001, 0b10010, 0b10100, 0b11000, 0b10100, 0b10010, 0b10001}, // K
    {0b10000, 0b10000, 0b10000, 0b10000, 0b10000, 0b10000, 0b11111}, // L
    {0b10001, 0b11011, 0b10101, 0b10001, 0b10001, 0b10001, 0b10001}, // M
    {0b10001, 0b10001, 0b11001, 0b10101, 0b10011, 0b10001, 0b10001}, // N
    {0b01110, 0b10001, 0b10001, 0b10001, 0b10001, 0b10001, 0b01110}, // O
    {0b11110, 0b10001, 0b10001, 0b11110, 0b10000, 0b10000, 0b10000}, // P
    {0b01110, 0b10001, 0b10001, 0b10001, 0b10101, 0b10010, 0b01101}, // Q
    {0b11110, 0b10001, 0b10001, 0b11110, 0b10100, 0b10010, 0b10001}, // R
    {0b01111, 0b10000, 0b10000, 0b01110, 0b00001, 0b00001, 0b11110}, // S
    {0b11111, 0b00100, 0b00100, 0b00100, 0b00100, 0b00100, 0b00100}, // T
    {0b10001, 0b10001, 0b10001, 0b10001, 0b10001, 0b10001, 0b01110}, // U
    {0b10001, 0b10001, 0b10001, 0b10001, 0b10001, 0b01010, 0b00100}, // V
    {0b10001, 0b10001, 0b10001, 0b10101, 0b10101, 0b10101, 0b01010}, // W
    {0b10001, 0b10001, 0b01010, 0b00100, 0b01010, 0b10001, 0b10001}, // X
    {0b10001, 0b10001, 0b10001, 0b01010, 0b00100, 0b00100, 0b00100}, // Y
    {0b11111, 0b00001, 0b00010, 0b00100, 0b01000, 0b10000, 0b11111}, // Z
    {0b01110, 0b10001, 0b10001, 0b10001, 0b10001, 0b10001, 0b01110}, // 0
    {0b00100, 0b01100, 0b00100, 0b00100, 0b00100, 0b00100, 0b01110}, // 1
    {0b01110, 0b10001, 0b00001, 0b00110, 0b01000, 0b10000, 0b11111}, // 2
    {0b01110, 0b10001, 0b00001, 0b00110, 0b00001, 0b10001, 0b01110}, // 3
    {0b00010, 0b00110, 0b01010, 0b10010, 0b11111, 0b00010, 0b00010}, // 4
    {0b11111, 0b10000, 0b11110, 0b00001, 0b00001, 0b10001, 0b01110}, // 5
    {0b00110, 0b01000, 0b10000, 0b11110, 0b10001, 0b10001, 0b01110}, // 6
    {0b11111, 0b00001, 0b00010, 0b00100, 0b01000, 0b01000, 0b01000}, // 7
    {0b01110, 0b10001, 0b10001, 0b01110, 0b10001, 0b10001, 0b01110}, // 8
    {0b01110, 0b10001, 0b10001, 0b01111, 0b00001, 0b00010, 0b01100}  // 9
  };

  int x_start_top = 10;
  int y_start_top = 10;
  int text_top_len = strlen(text_top);

  for (int c = 0; c < text_top_len; c++) {
    int char_index = -1;
    if (text_top[c] >= 'A' && text_top[c] <= 'Z') char_index = text_top[c] - 'A';
    else if (text_top[c] >= '0' && text_top[c] <= '9') char_index = (text_top[c] - '0') + 26;
    if (char_index >= 0) {
      for (int y = 0; y < 7; y++) {
        for (int x = 0; x < 5; x++) {
          if (font[char_index][y] & (1 << (4 - x))) {
            for (int dy = 0; dy < 2; dy++) {
              for (int dx = 0; dx < 2; dx++) {
                int pixel_x = x_start_top + (c * (char_width + spacing)) + (x * 2) + dx;
                int pixel_y = y_start_top + (y * 2) + dy;
                if (pixel_x < width && pixel_y < height) {
                  int index = (pixel_y * width + pixel_x) * 3;
                  rgb_buf[index + 0] = TOP_B;
                  rgb_buf[index + 1] = TOP_G;
                  rgb_buf[index + 2] = TOP_R;
                }
              }
            }
          }
        }
      }
    }
  }

  int text_bottom_len = strlen(text_bottom);
  int x_start_bottom = width - (text_bottom_len * (char_width + spacing)) - 10;
  int y_start_bottom = height - char_height - 10;

  for (int c = 0; c < text_bottom_len; c++) {
    int char_index = -1;
    if (text_bottom[c] >= 'A' && text_bottom[c] <= 'Z') char_index = text_bottom[c] - 'A';
    else if (text_bottom[c] >= '0' && text_bottom[c] <= '9') char_index = (text_bottom[c] - '0') + 26;
    if (char_index >= 0) {
      for (int y = 0; y < 7; y++) {
        for (int x = 0; x < 5; x++) {
          if (font[char_index][y] & (1 << (4 - x))) {
            for (int dy = 0; dy < 2; dy++) {
              for (int dx = 0; dx < 2; dx++) {
                int pixel_x = x_start_bottom + (c * (char_width + spacing)) + (x * 2) + dx;
                int pixel_y = y_start_bottom + (y * 2) + dy;
                if (pixel_x < width && pixel_y < height && pixel_x >= 0) {
                  int index = (pixel_y * width + pixel_x) * 3;
                  rgb_buf[index + 0] = BTM_B;
                  rgb_buf[index + 1] = BTM_G;
                  rgb_buf[index + 2] = BTM_R;
                }
              }
            }
          }
        }
      }
    }
  }
}

void doImage() {
  camera_fb_t* fb = nullptr;
  // Skip first N frames.
  for (int i = 0; i < 3; i++) {
    fb = esp_camera_fb_get();
    esp_camera_fb_return(fb);
    fb = nullptr;
  }
  
  delay(1000);
  #ifdef USE_FLASH 
    digitalWrite(LED_FLASH,HIGH);
  #endif
  
  fb = esp_camera_fb_get();

  #ifdef USE_FLASH 
    digitalWrite(LED_FLASH,LOW);
  #endif
  delay(1000);
  
  if (!fb) {
    Serial.println("Camera capture failed");
    return;
  }

  rgb_width = fb->width;
  rgb_height = fb->height;
  rgb_buf_len = rgb_width * rgb_height * 3 * sizeof(uint8_t);
  Serial.printf("Size:%ix%i*3=%i\n", rgb_width, rgb_height, rgb_buf_len);

  if (!rgb_buf) {
    rgb_buf = (uint8_t *)malloc(rgb_buf_len);
    Serial.println("RGB buff allocated");
  } else {
    Serial.println("RGB buff already allocated");
  }
  if (!rgb_buf) {
    Serial.println("RGB buff allocation failed");
    return;
  }

  fmt2rgb888(fb->buf, fb->len, fb->format, rgb_buf);
  drawText(rgb_buf, rgb_width, rgb_height, overlayTextTop.c_str(), overlayTextBottom.c_str());

  if (currentSSTV) delete currentSSTV;
  currentSSTV = new SSTV_config_t(44);
  Serial.print("Sending image");

  // Activate PTT
  Serial.println(" - Activating PTT");
  digitalWrite(PTT_PIN, HIGH);

  SSTVtime = 0; SSTVnext = 0; SSTVseq = 0; SSTV_RUNNING = true;
  vTaskResume(sampleHandlerHandle);
  while (SSTV_RUNNING) {
    Serial.print(".");
    delay(1000);
  }
  esp_task_wdt_reset();
  enableCore0WDT();
  vTaskSuspend(sampleHandlerHandle);
  Serial.println("Ok.123");

  // Deactivate PTT (LOW = inactive)
  Serial.println(" - Deactivating PTT");
  digitalWrite(PTT_PIN, LOW);

  esp_camera_fb_return(fb);
  ledcDetach(SPEAKER_OUTPUT); // this to really "shutup" the pin

  // Free the buffer after use
  free(rgb_buf);
  rgb_buf = NULL;
}

void setup() {
  Serial.begin(115200);
  delay(1000);

  //shutdown WiFi completely
  WiFi.disconnect(true);
  WiFi.mode(WIFI_OFF);

  //Print the wakeup reason for ESP32
  print_wakeup_reason();

  if (capt_frame) {
    setupCamera();

    //pinMode(CAPT_BTN, INPUT_PULLUP);
    pinMode(LED_FLASH, OUTPUT);
    pinMode(LED_RED, OUTPUT);
    pinMode(PTT_PIN, OUTPUT); // Configure PTT as output
    pinMode(BUZZER_PIN, OUTPUT);
    digitalWrite(LED_FLASH, LOW);
    digitalWrite(LED_RED, HIGH);
    rtc_gpio_hold_dis((gpio_num_t)PTT_PIN);
    digitalWrite(PTT_PIN, LOW); // PTT inactive at startup
  
    hw_timer_t *timer = NULL;
    timer = timerBegin(10000000);
    timerAttachInterrupt(timer, &audioISR);
    timerAlarm(timer, 10000000 / F_SAMPLE, true, 0);
  
    ledcAttach(SPEAKER_OUTPUT, 200000, LEDC_TIMER_8_BIT);
  
    xTaskCreatePinnedToCore(sampleHandler, "IN", 4096, NULL, 1, &sampleHandlerHandle, 0);
    vTaskSuspend(sampleHandlerHandle);
    tone(BUZZER_PIN, 500, 100);
    tone(BUZZER_PIN, 440, 100);
    doImage();
    tone(BUZZER_PIN, 440, 100);
    tone(BUZZER_PIN, 480, 100);
    tone(BUZZER_PIN, 500, 100);
    capt_frame = false;
  }

  esp_sleep_enable_ext0_wakeup(CAPT_BTN, 0);  //1 = High, 0 = Low
  // Configure pullup/downs via RTCIO to tie wakeup pins to inactive level during deepsleep.
  // EXT0 resides in the same power domain (RTC_PERIPH) as the RTC IO pullup/downs.
  // No need to keep that power domain explicitly, unlike EXT1.

  //rtc_gpio_pullup_dis(CAPT_BTN); //Uncomment these 2 lines for pull-down resistor, comment for pull-up
  //rtc_gpio_pulldown_en(CAPT_BTN);

  rtc_gpio_pullup_en(CAPT_BTN); //Comment these 2 lines for pull-down resistor, uncomment for pull-up
  rtc_gpio_pulldown_dis(CAPT_BTN);
  
  //Go to sleep now
  Serial.println("Going to sleep now");
  rtc_gpio_hold_en((gpio_num_t)PTT_PIN); // hold PTT_PIN state during deepsleep
  esp_deep_sleep_start();
  
}

void loop() {}

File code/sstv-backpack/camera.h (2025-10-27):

#ifndef __CAMERA_H
#define __CAMERA_H

#include "esp_camera.h"

#define PWDN_GPIO_NUM     32
#define RESET_GPIO_NUM    -1
#define XCLK_GPIO_NUM      0
#define SIOD_GPIO_NUM     26
#define SIOC_GPIO_NUM     27

#define Y9_GPIO_NUM       35
#define Y8_GPIO_NUM       34
#define Y7_GPIO_NUM       39
#define Y6_GPIO_NUM       36
#define Y5_GPIO_NUM       21
#define Y4_GPIO_NUM       19
#define Y3_GPIO_NUM       18
#define Y2_GPIO_NUM        5
#define VSYNC_GPIO_NUM    25
#define HREF_GPIO_NUM     23
#define PCLK_GPIO_NUM     22



void setupCamera()
{
  esp_camera_deinit();

  camera_config_t config;
  config.ledc_channel = LEDC_CHANNEL_0;
  config.ledc_timer = LEDC_TIMER_0;
  config.pin_d0 = Y2_GPIO_NUM;
  config.pin_d1 = Y3_GPIO_NUM;
  config.pin_d2 = Y4_GPIO_NUM;
  config.pin_d3 = Y5_GPIO_NUM;
  config.pin_d4 = Y6_GPIO_NUM;
  config.pin_d5 = Y7_GPIO_NUM;
  config.pin_d6 = Y8_GPIO_NUM;
  config.pin_d7 = Y9_GPIO_NUM;
  config.pin_xclk = XCLK_GPIO_NUM;
  config.pin_pclk = PCLK_GPIO_NUM;
  config.pin_vsync = VSYNC_GPIO_NUM;
  config.pin_href = HREF_GPIO_NUM;
  config.pin_sscb_sda = SIOD_GPIO_NUM;
  config.pin_sscb_scl = SIOC_GPIO_NUM;
  config.pin_pwdn = PWDN_GPIO_NUM;
  config.pin_reset = RESET_GPIO_NUM;
  config.xclk_freq_hz = 20000000;
  config.pixel_format = PIXFORMAT_JPEG;
  //config.pixel_format = PIXFORMAT_RGB565;
  //config.pixel_format = PIXFORMAT_RGB888;
  //config.pixel_format = PIXFORMAT_GRAYSCALE;
  //init with high specs to pre-allocate larger buffers
  //config.frame_size = FRAMESIZE_QQVGA;
  config.frame_size = FRAMESIZE_QVGA;//320x240
  config.fb_count = 1;
  config.grab_mode = CAMERA_GRAB_WHEN_EMPTY;
  config.fb_location = CAMERA_FB_IN_PSRAM;
  config.jpeg_quality = 10; // 10.best 63.worst
  config.fb_count = 1;
/*
  if (psramFound()) {
    config.frame_size = FRAMESIZE_UXGA;
    config.jpeg_quality = 10;
    config.fb_count = 2;
  }
  */
  /*
    if (psramFound()) {
    config.frame_size = FRAMESIZE_UXGA;
    config.jpeg_quality = 10;
    config.fb_count = 2;
    //Serial.println("Psram");
    } else {
    config.frame_size = FRAMESIZE_SVGA;
    config.jpeg_quality = 12;
    config.fb_count = 1;
    }
  */

#if defined(CAMERA_MODEL_ESP_EYE)
  pinMode(13, INPUT_PULLUP);
  pinMode(14, INPUT_PULLUP);
#endif
  // camera init
  esp_err_t err = esp_camera_init(&config);
  if (err != ESP_OK) {
    Serial.printf("Camera init failed with error 0x%x", err);
    return;
  }
  sensor_t * s = esp_camera_sensor_get();
  
  // General settings *STANDARD*
  s->set_quality(s, 10);          // 0-63, lower is higher quality. Start at 16 for a balance of file size and quality.
  s->set_contrast(s, 0);          // -2 to 2, 0 is default
  s->set_brightness(s, 0);        // -2 to 2, 0 is default
  s->set_saturation(s, 0);        // -2 to 2, 0 is default
  s->set_special_effect(s, 0);    // 0 = No Effect
  
  // White balance
  s->set_whitebal(s, 1);          // 1 = enable AWB
  s->set_awb_gain(s, 1);          // 1 = enable AWB gain control
  s->set_wb_mode(s, 0);           // 0 = Auto white balance
  
  // Exposure and gain control
  s->set_exposure_ctrl(s, 1);     // 1 = enable auto exposure control (AEC)
  s->set_aec2(s, 0);              // 0 = disable AEC2 (reduces banding)
  s->set_ae_level(s, 0);          // -2 to 2, 0 is default
  s->set_aec_value(s, 300);       // Auto exposure value. Can be set manually if AEC is off.
  s->set_gain_ctrl(s, 1);         // 1 = enable auto gain control (AGC)
  s->set_agc_gain(s, 0);          // 0 = auto gain value. Can be set manually if AGC is off.
  s->set_gainceiling(s, (gainceiling_t)4); // 4 = 16x gain. Adjust as needed.
  
  // Other adjustments
  s->set_lenc(s, 1);              // 1 = enable lens correction (LENC)
  s->set_bpc(s, 1);               // 1 = enable black pixel correction (BPC)
  s->set_wpc(s, 1);               // 1 = enable white pixel correction (WPC)
  s->set_raw_gma(s, 1);           // 1 = enable gamma correction
/*
 // General settings *OUTDOOR*
  s->set_quality(s, 10);          // 0-63, lower is higher quality. Start at 16 for a balance of file size and quality.
  s->set_contrast(s, 0);          // -2 to 2, 0 is default
  s->set_brightness(s, 0);        // -2 to 2, 0 is default
  s->set_saturation(s, 1);        // -2 to 2, 0 is default
  s->set_special_effect(s, 0);    // 0 = No Effect
  
  // White balance
  s->set_whitebal(s, 1);          // 1 = enable AWB
  s->set_awb_gain(s, 1);          // 1 = enable AWB gain control
  s->set_wb_mode(s, 0);           // 0 = Auto white balance
  
  // Exposure and gain control
  s->set_exposure_ctrl(s, 0);     // 1 = enable auto exposure control (AEC)
  s->set_aec2(s, 0);              // 0 = disable AEC2 (reduces banding)
  s->set_ae_level(s, 0);          // -2 to 2, 0 is default
  s->set_aec_value(s, 12);       // Auto exposure value. Can be set manually if AEC is off.
  s->set_gain_ctrl(s, 0);         // 1 = enable auto gain control (AGC)
  s->set_agc_gain(s, 0);          // 0 = auto gain value. Can be set manually if AGC is off.
  s->set_gainceiling(s, (gainceiling_t)4); // 4 = 16x gain. Adjust as needed.
  
  // Other adjustments
  s->set_lenc(s, 1);              // 1 = enable lens correction (LENC)
  s->set_bpc(s, 1);               // 1 = enable black pixel correction (BPC)
  s->set_wpc(s, 1);               // 1 = enable white pixel correction (WPC)
  s->set_raw_gma(s, 1);           // 1 = enable gamma correction
*/
  
  //initial sensors are flipped vertically and colors are a bit saturated
  if (s->id.PID == OV3660_PID) {
    s->set_vflip(s, 1);//flip it back
    s->set_brightness(s, 1);//up the blightness just a bit
    s->set_saturation(s, -2);//lower the saturation
  }
  //drop down frame size for higher initial frame rate
  //  s->set_framesize(s, FRAMESIZE_QVGA);

#if defined(CAMERA_MODEL_M5STACK_WIDE)
  s->set_vflip(s, 1);
  s->set_hmirror(s, 1);
#endif

}
#endif

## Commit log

2025-08-24 Add initial files
    [sstv-backpack.kicad_pcb, sstv-backpack.kicad_sch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]
2025-08-25 Update silkscreen and gerbers
    [sstv-backpack.kicad_pcb, sstv-backpack.kicad_sch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]
2025-09-08 Fix v1.0, add v1.1, and restructure
    [sstv-backpack.csv, sstv-backpack.ipt, sstv-backpack.kicad_pcb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]
2025-09-09 Fix BOMs and update README
    [sstv-backpack.csv]
2025-09-21 Swap v1.1 to USB-C and add v1.2
    Swapped v1.1 to USB-C from USB Mini B, added the TX transmit transistor to hopefully fix the TX hang, and added the WIP files for v1.2
    [sstv-backpack.csv, sstv-backpack.kicad_pcb, sstv-backpack.kicad_sch]
2025-09-22 Update v1.1 gerber and BOM
    [sstv-backpack.csv, sstv-backpack.kicad_pcb]
2025-10-20 Fix PCB and add USB-C to case
    [sstv-backpack.ipt, sstv-backpack.kicad_pcb, sstv-backpack.kicad_sch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]
2025-10-21 Arduino Core upgrade
    Now compiles with no problems in Arduino Core v3.0.7
    [sstv-backpack.ino]
2025-10-21 Fix pin naming and update camera settings
    Now you can tweak the sensor parameters as in the "CameraWeb" example
    [camera.h]
2025-10-21 Revise README for ESP32 setup
    Updated installation instructions and board settings for clarity.
    Now works with ArduinoCore v3.0.7
2025-10-21 Fix SCCB pin names and update camera configurations
    Corrected pin names for SCCB interface and adjusted camera settings.
    [camera.h]
2025-10-21 Fix typo in SCCB pin configuration
    The only fix needed for your camera.h is this one
    [camera.h]
2025-10-21 Revise README for ArduinoCore V3.0.7+ compatibility
    Updated README to reflect compatibility with ArduinoCore V3.0.7+ and clarified upgrade notes.
2025-10-21 Fix pin naming and optimize camera settings
    Optimised camera settings for home and daylight.
    This sensor isn't brillinat in low light, do not expect great results
    [camera.h]
2025-10-21 Update camera settings in camera.h
    Commented out gain ceiling setting for AGC.
2025-10-21 Revise upgrade notes for ArduinoCore V3.0.7+
    Updated upgrade instructions for ArduinoCore compatibility and improved timer management details.
2025-10-21 Update README with camera profile selection details
    Added information about selecting camera profiles in camera.h.
2025-10-21 Enable gamma correction in camera settings
    [camera.h]
2025-10-21 Fix SPEAKER_OUT pin name to SPEAKER_OUTPUT
    [sstv-backpack.ino]
2025-10-22 Stop PWM on LEDC channel 3
    Stop PWM on LEDC channel 3 to silence the pin.
2025-10-22 Refactor camera settings for improved performance
    Camera settings are CRUCIAL if you are using OV2640 sensor (that's an extremely slow one in agc, so carefully tune the parameters before use!!)
2025-10-22 Update README and code for PTT
    [sstv-backpack.kicad_pcb, sstv-backpack.kicad_sch, uv-5r-back.ipt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]
2025-10-22 Change file naming for PCBS and add v1.0.1
    [sstv-backpack-v1.0-B_Cu.gbr, sstv-backpack-v1.0-B_Mask.gbr, sstv-backpack-v1.0-B_Paste.gbr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]
2025-10-22 Remove temp files and update .gitignore
    [sstv-backpack-v1.0-B_Cu.gbr, sstv-backpack-v1.0-B_Mask.gbr, sstv-backpack-v1.0-B_Paste.gbr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]
2025-10-22 Update assembly parts in README
2025-10-23 Update README with clearer camera settings instructions
    Clarify instructions for modifying camera settings in camera.h.
2025-10-24 Refactor audio output handling with ledcWrite
    Now the LEDC code is V3.x.x compliant (use the new APIs)
2025-10-25 Fix definition for SPEAKER_OUTPUT
    [sstv-backpack.ino]
2025-10-25 Comment out outdoor settings in camera.h
    Commented out general settings and adjustments for outdoor use in camera.h.
2025-10-28 Refactor sstv-backpack.ino and add deepsleep and wakeup from EXT source
    Refactor code structure and add deepsleep/wakeup functions.
    Now the camera goes in deepsleep when power on, waiting for user input on GPIO_NUM_xx pin for wake up and take a shot.
    In this way you can maximize battery life.
2025-10-28 Fix line number for CAPT_BTN wiring upgrade instruction
    Updated line numbers for CAPT_BTN wiring instructions in README.
2025-10-29 Add capture tones and make button match
2025-10-29 Update line numbers in README and fix defaults
    [sstv-backpack.ino]
2025-10-29 Rename v1.0.1 BOM
    [sstv-backpack-v1.0.1.csv]
2025-10-29 Fix BOM links
2025-11-09 Update README and add pull-down resistors for PTT
    [sstv-backpack-v1.0.1.csv, sstv-backpack-v1.0.1.kicad_pcb, sstv-backpack-v1.0.1.kicad_sch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]
2025-11-09 Add v1.1.1 with CH340C and update README
    [sstv-backpack-v1.1.1.csv, sstv-backpack-v1.1.1.kicad_pcb, sstv-backpack-v1.1.1.kicad_sch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]
2025-11-14 Add STEP file for case
    [uv-5r-back.stp]
2025-11-21 Create universal case and add Baofeng 5RM
    [5RM_batt_conn.ipt, 5RM_batt_conn.stl, 5RM_belt_clip.ipt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]
2025-11-21 Update 5RM battery STL
    [5RM_batt_conn.stl]
2025-11-22 Add button and switch extension for front case
    [button.ipt, button.stl, switch.ipt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]
